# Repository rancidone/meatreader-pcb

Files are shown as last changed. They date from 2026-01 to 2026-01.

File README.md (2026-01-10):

# ESP32 Wireless Thermometer

## Overview
This project is a **custom, battery-powered ESP32-based wireless thermometer** designed for BBQ and probe-based temperature monitoring.

The goal is to build a **robust, safe, and manufacturable device** suitable for real-world use, not a development board or a proof-of-concept. The design prioritizes reliability, serviceability, and clear engineering tradeoffs over extreme miniaturization or feature creep.

---

## Project Goals
- Battery-powered operation using a single-cell Li-ion / LiPo battery
- 24+ hour runtime under typical use
- In-place battery charging via USB-C (power only)
- Wireless connectivity (Wi-Fi required, BLE optional)
- OTA firmware update capability
- Support for multiple external thermistor probes
- Safe hot-plugging of all external connectors
- Outdoor and kitchen-safe electrical robustness
- Aluminum enclosure compatibility with minimal machining tools
- Low-cost, reproducible manufacturing
- Friendly to both SMT assembly and hand soldering

---

## Design Philosophy
This project is guided by the following principles:

- **Safety first**  
  All external connections must tolerate hot-plugging, static discharge, and user error without damaging the device.

- **Manufacturable by design**  
  Components and footprints are selected with real-world assembly in mind, favoring widely available parts and avoiding unnecessary complexity.

- **Debuggable and understandable**  
  The design should be easy to inspect, measure, and troubleshoot without specialized equipment.

- **Incremental improvement**  
  Revisions build on known-good designs, preserving proven circuits while improving specific areas as needed.

---

## Non-Goals
The following are explicitly out of scope:
- USB data or USB-PD support
- Power-bank or device-charging functionality
- Ultra-miniaturized or wearable form factors
- Dev-board style layouts
- Feature-driven complexity that compromises reliability

---

## Repository Structure
This repository contains the hardware design files and supporting documentation for the project.

Typical contents include:
- KiCad schematics and PCB layouts
- Project-local symbol and footprint libraries
- Design notes and revision history
- Manufacturing and assembly references

Generated outputs (Gerbers, fabrication files, temporary caches) are not tracked unless explicitly required.

---

## Status
This repository contains an evolving hardware design with multiple revisions. Earlier revisions serve as validated references; newer revisions focus on improved power handling, manufacturability, and long-term reliability.

---

## License
This project is intended for personal, educational, and hobbyist use. Licensing details may be added as the design matures.

---

## Acknowledgements
This project draws on common, well-established embedded hardware design patterns and prioritizes practical engineering over novelty.

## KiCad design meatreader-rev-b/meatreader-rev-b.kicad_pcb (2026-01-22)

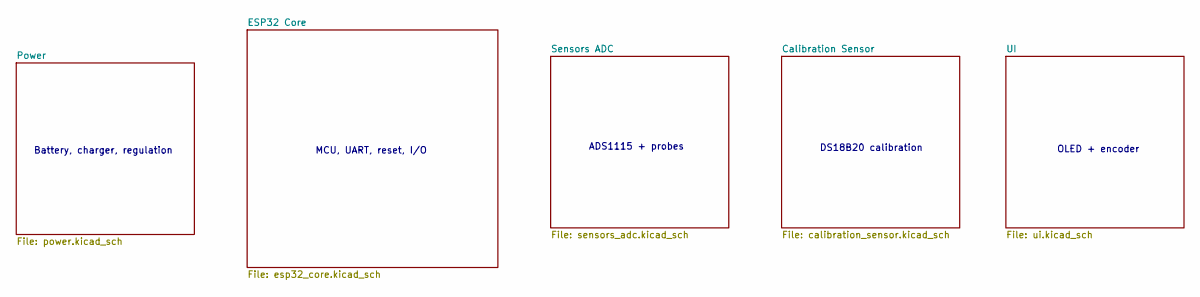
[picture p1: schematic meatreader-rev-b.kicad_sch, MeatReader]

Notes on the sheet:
MCU, UART, reset, I/O
ADS1115 + probes
OLED + encoder
Battery, charger, regulation
DS18B20 calibration

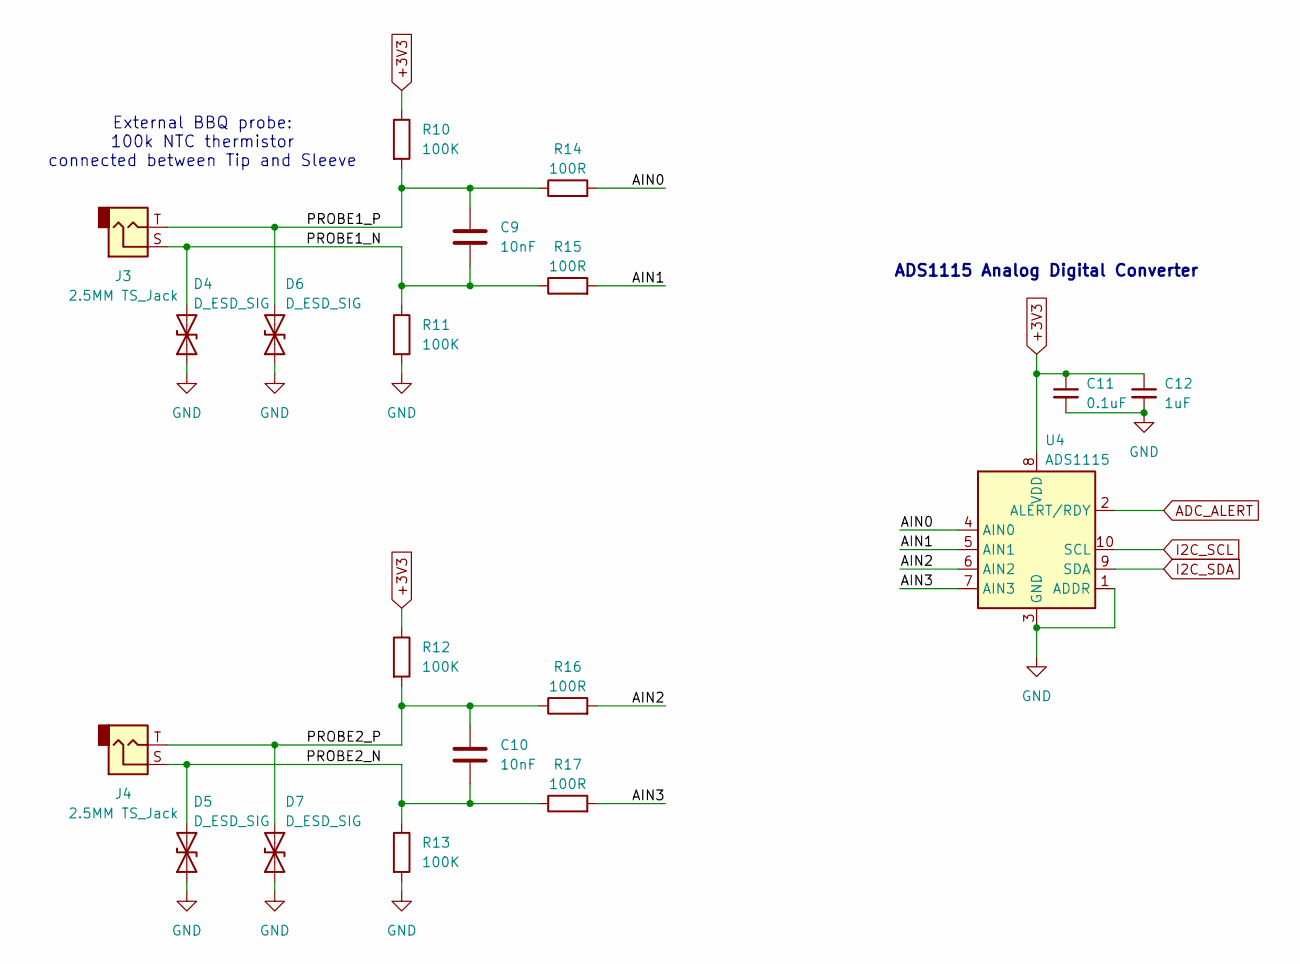
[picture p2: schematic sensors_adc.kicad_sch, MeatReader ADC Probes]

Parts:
C9, C10: 10nF; C_0603_1608Metric
C11: 0.1uF; C_0603_1608Metric
C12: 1uF; C_0603_1608Metric
D4, D5: D_ESD_SIG; D_0402_1005Metric; LCSC C20615778
D6, D7: D_ESD_SIG; D_0402_1005Metric
J3, J4: 2.5MM TS_Jack; Jack_2.5MM_PJ210B_TS; JLC_3DModel_Q 9e36057968d7478ca8658f227985305d
R10, R11, R12, R13: 100K; R_0603_1608Metric
R14, R15, R16, R17: 100R; R_0603_1608Metric
U4: ADS1115; TSSOP-10_3x3mm_P0.5mm

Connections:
+3V3: C11.1, C12.1, R10.1, R12.1, U4.8 (VDD); also elsewhere on the board
/Sensors ADC/AIN0: R14.2, U4.4 (AIN0)
/Sensors ADC/AIN1: R15.2, U4.5 (AIN1)
/Sensors ADC/AIN2: R16.2, U4.6 (AIN2)
/Sensors ADC/AIN3: R17.2, U4.7 (AIN3)
/Sensors ADC/PROBE1_N: C9.2, D4.2 (A2), J3.S, R11.1, R15.1
/Sensors ADC/PROBE1_P: C9.1, D6.2 (A2), J3.T, R10.2, R14.1
/Sensors ADC/PROBE2_N: C10.2, D5.2 (A2), J4.S, R13.1, R17.1
/Sensors ADC/PROBE2_P: C10.1, D7.2 (A2), J4.T, R12.2, R16.1
ADC_ALERT: U4.2 (ALERT/RDY); also elsewhere on the board
GND: C11.2, C12.2, D4.1 (A1), D5.1 (A1), D6.1 (A1), D7.1 (A1), R11.2, R13.2, U4.1 (ADDR), U4.3 (GND); also elsewhere on the board
I2C_SCL: U4.10 (SCL); also elsewhere on the board
I2C_SDA: U4.9 (SDA); also elsewhere on the board

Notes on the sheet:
External BBQ probe: 100k NTC thermistor connected between Tip and Sleeve
ADS1115 Analog Digital Converter

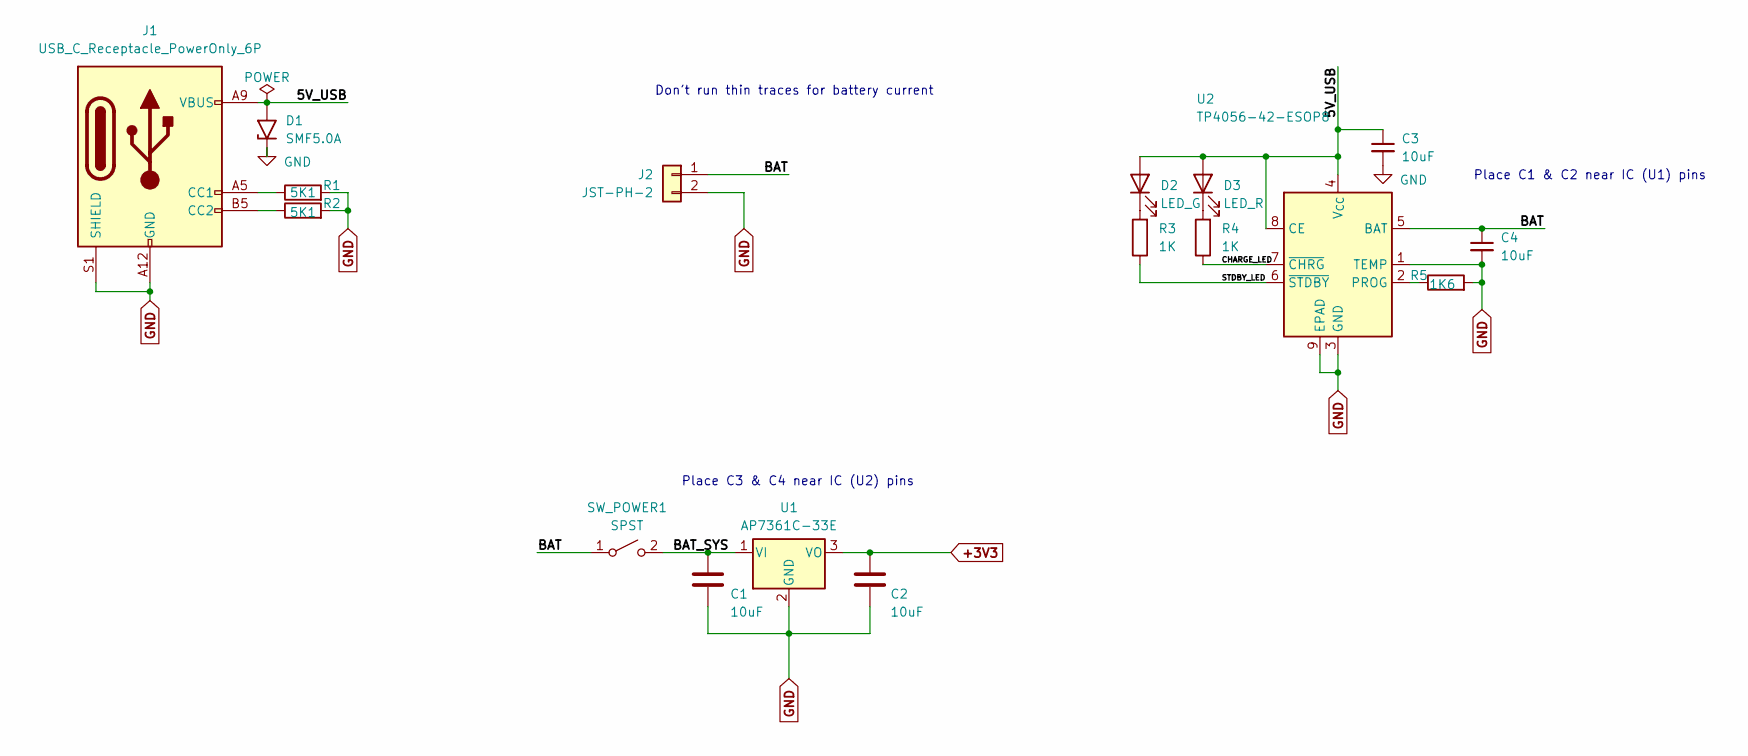
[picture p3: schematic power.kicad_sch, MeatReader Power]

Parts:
C1, C2, C3, C4: 10uF; C_0805_2012Metric
D1: SMF5.0A; D_SMF; LCSC C19077497
D2: LED_G; LED_D3.0mm
D3: LED_R; LED_D3.0mm
J1: USB_C_Receptacle_PowerOnly_6P; USB_C_Receptacle_HRO_TYPE-C-31-M-12
J2: JST-PH-2; JST_PH_B2B-PH-K_1x02_P2.00mm_Vertical
R1, R2: 5K1; R_0402_1005Metric
R3, R4: 1K; R_0402_1005Metric; LCSC C11702
R5: 1K6; R_0402_1005Metric
SW_POWER1: SPST; PinHeader_1x02_P2.54mm_Vertical
U1: AP7361C-33E; SOT-223-3_TabPin2
U2: TP4056-42-ESOP8; SOIC-8-1EP_3.9x4.9mm_P1.27mm_EP2.41x3.3mm

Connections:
+3V3: C2.1, U1.3 (VO); also elsewhere on the board
/Power/5V_USB: C3.1, D1.2 (A2), D2.2 (A), D3.2 (A), J1.A9 (VBUS), J1.B9 (VBUS), U2.4 (V_{CC}), U2.8 (CE)
/Power/BAT: C4.1, J2.1, SW_POWER1.1 (A), U2.5 (BAT)
/Power/BAT_SYS: C1.1, SW_POWER1.2 (B), U1.1 (VI)
/Power/CHARGE_LED: R4.1, U2.7 (~CHRG)
/Power/STDBY_LED: R3.1, U2.6 (~STDBY)
GND: C1.2, C2.2, C3.2, C4.2, D1.1 (A1), J1.A12 (GND), J1.B12 (GND), J1.S1 (SHIELD), J2.2, R1.2, R2.2, R5.2, U1.2 (GND), U2.1 (TEMP), U2.3 (GND), U2.9 (EPAD); also elsewhere on the board
unnamed: D2.1 (K), R3.2
unnamed: D3.1 (K), R4.2
unnamed: J1.A5 (CC1), R1.1
unnamed: J1.B5 (CC2), R2.1
unnamed: R5.1, U2.2 (PROG)

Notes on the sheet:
Don't run thin traces for battery current
Place C1 & C2 near IC (U1) pins
Place C3 & C4 near IC (U2) pins

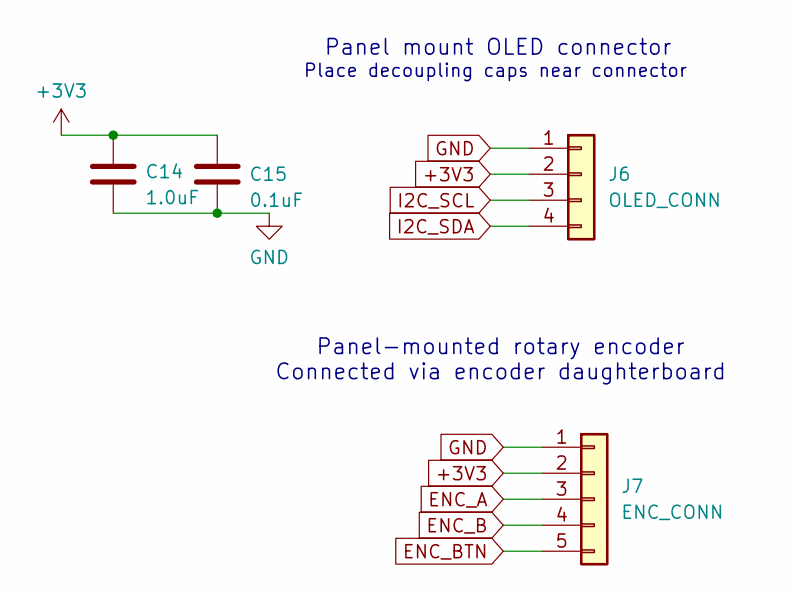
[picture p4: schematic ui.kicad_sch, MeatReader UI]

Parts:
C14: 1.0uF; C_0603_1608Metric
C15: 0.1uF; C_0603_1608Metric
J6: OLED_CONN; JST_XH_B4B-XH-AM_1x04_P2.50mm_Vertical
J7: ENC_CONN; JST_XH_B5B-XH-AM_1x05_P2.50mm_Vertical

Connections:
+3V3: C14.1, C15.1, J6.2, J7.2; also elsewhere on the board
ENC_A: J7.3; also elsewhere on the board
ENC_B: J7.4; also elsewhere on the board
ENC_BTN: J7.5; also elsewhere on the board
GND: C14.2, C15.2, J6.1, J7.1; also elsewhere on the board
I2C_SCL: J6.3; also elsewhere on the board
I2C_SDA: J6.4; also elsewhere on the board

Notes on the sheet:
Panel-mounted rotary encoder Connected via encoder daughterboard
Place decoupling caps near connector
Panel mount OLED connector

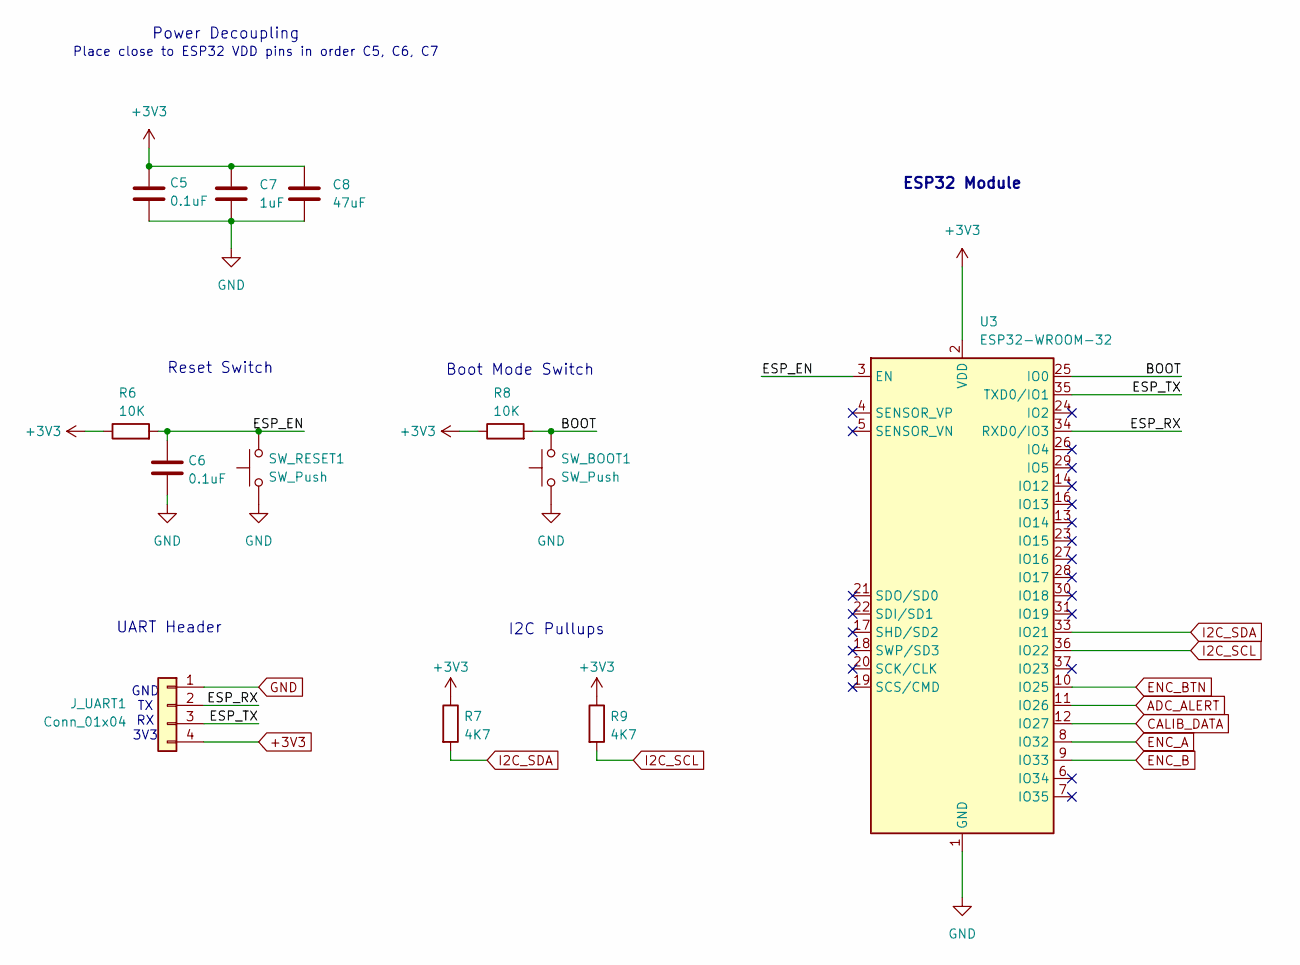
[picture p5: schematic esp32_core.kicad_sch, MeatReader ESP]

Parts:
C5, C6: 0.1uF; C_0603_1608Metric
C7: 1uF; C_0603_1608Metric
C8: 47uF; C_0805_2012Metric
J_UART1: Conn_01x04; PinHeader_1x04_P2.54mm_Vertical
R6, R8: 10K; R_0603_1608Metric
R7, R9: 4K7; R_0603_1608Metric
SW_BOOT1: SW_Push; Test_01x02
SW_RESET1: SW_Push; SW_PUSH_6mm
U3: ESP32-WROOM-32; ESP32-WROOM-32_NoThermals

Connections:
+3V3: C5.1, C7.1, C8.1, J_UART1.4, R6.1, R7.1, R8.1, R9.1, U3.2 (VDD); also elsewhere on the board
/ESP32 Core/BOOT: R8.2, SW_BOOT1.2, U3.25 (IO0)
/ESP32 Core/ESP_EN: C6.1, R6.2, SW_RESET1.2, U3.3 (EN)
/ESP32 Core/ESP_RX: J_UART1.2, U3.34 (RXD0/IO3)
/ESP32 Core/ESP_TX: J_UART1.3, U3.35 (TXD0/IO1)
ADC_ALERT: U3.11 (IO26); also elsewhere on the board
CALIB_DATA: U3.12 (IO27); also elsewhere on the board
ENC_A: U3.8 (IO32); also elsewhere on the board
ENC_B: U3.9 (IO33); also elsewhere on the board
ENC_BTN: U3.10 (IO25); also elsewhere on the board
GND: C5.2, C6.2, C7.2, C8.2, J_UART1.1, SW_BOOT1.1, SW_RESET1.1, U3.1 (GND), U3.15 (GND), U3.38 (GND), U3.39 (GND); also elsewhere on the board
I2C_SCL: R9.2, U3.36 (IO22); also elsewhere on the board
I2C_SDA: R7.2, U3.33 (IO21); also elsewhere on the board

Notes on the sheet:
GND TX RX 3V3
I2C Pullups
UART Header
Power Decoupling
Place close to ESP32 VDD pins in order C5, C6, C7
Reset Switch
Boot Mode Switch
ESP32 Module

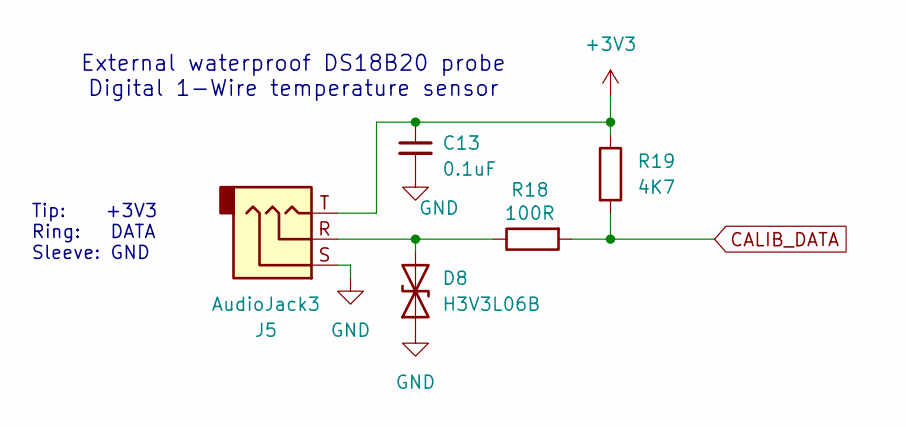
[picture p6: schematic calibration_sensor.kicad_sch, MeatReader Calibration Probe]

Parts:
C13: 0.1uF; C_0603_1608Metric
D8: H3V3L06B; D_0402_1005Metric
J5: AudioJack3; PJ-320A_TRS
R18: 100R; R_0603_1608Metric
R19: 4K7; R_0603_1608Metric

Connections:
+3V3: C13.1, J5.T, R19.1; also elsewhere on the board
CALIB_DATA: R18.2, R19.2; also elsewhere on the board
GND: C13.2, D8.1 (A1), J5.S; also elsewhere on the board
unnamed: D8.2 (A2), J5.R, R18.1

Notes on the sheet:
External waterproof DS18B20 probe Digital 1-Wire temperature sensor
Tip: +3V3 Ring: DATA Sleeve: GND

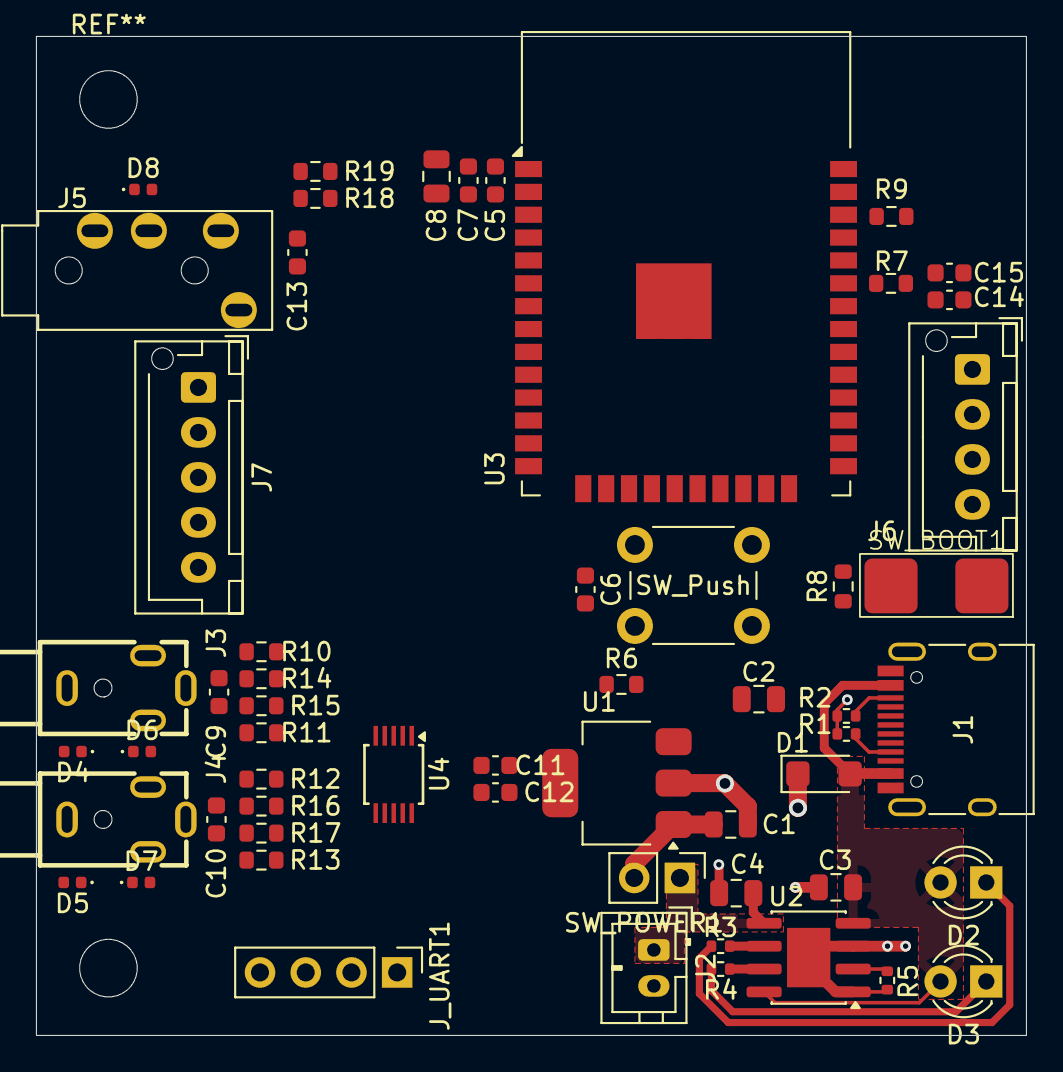
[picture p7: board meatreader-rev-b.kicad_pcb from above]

Board: 2 copper layers, 55.0 x 55.5 mm, 57 parts (0 on the bottom side), 32 nets.

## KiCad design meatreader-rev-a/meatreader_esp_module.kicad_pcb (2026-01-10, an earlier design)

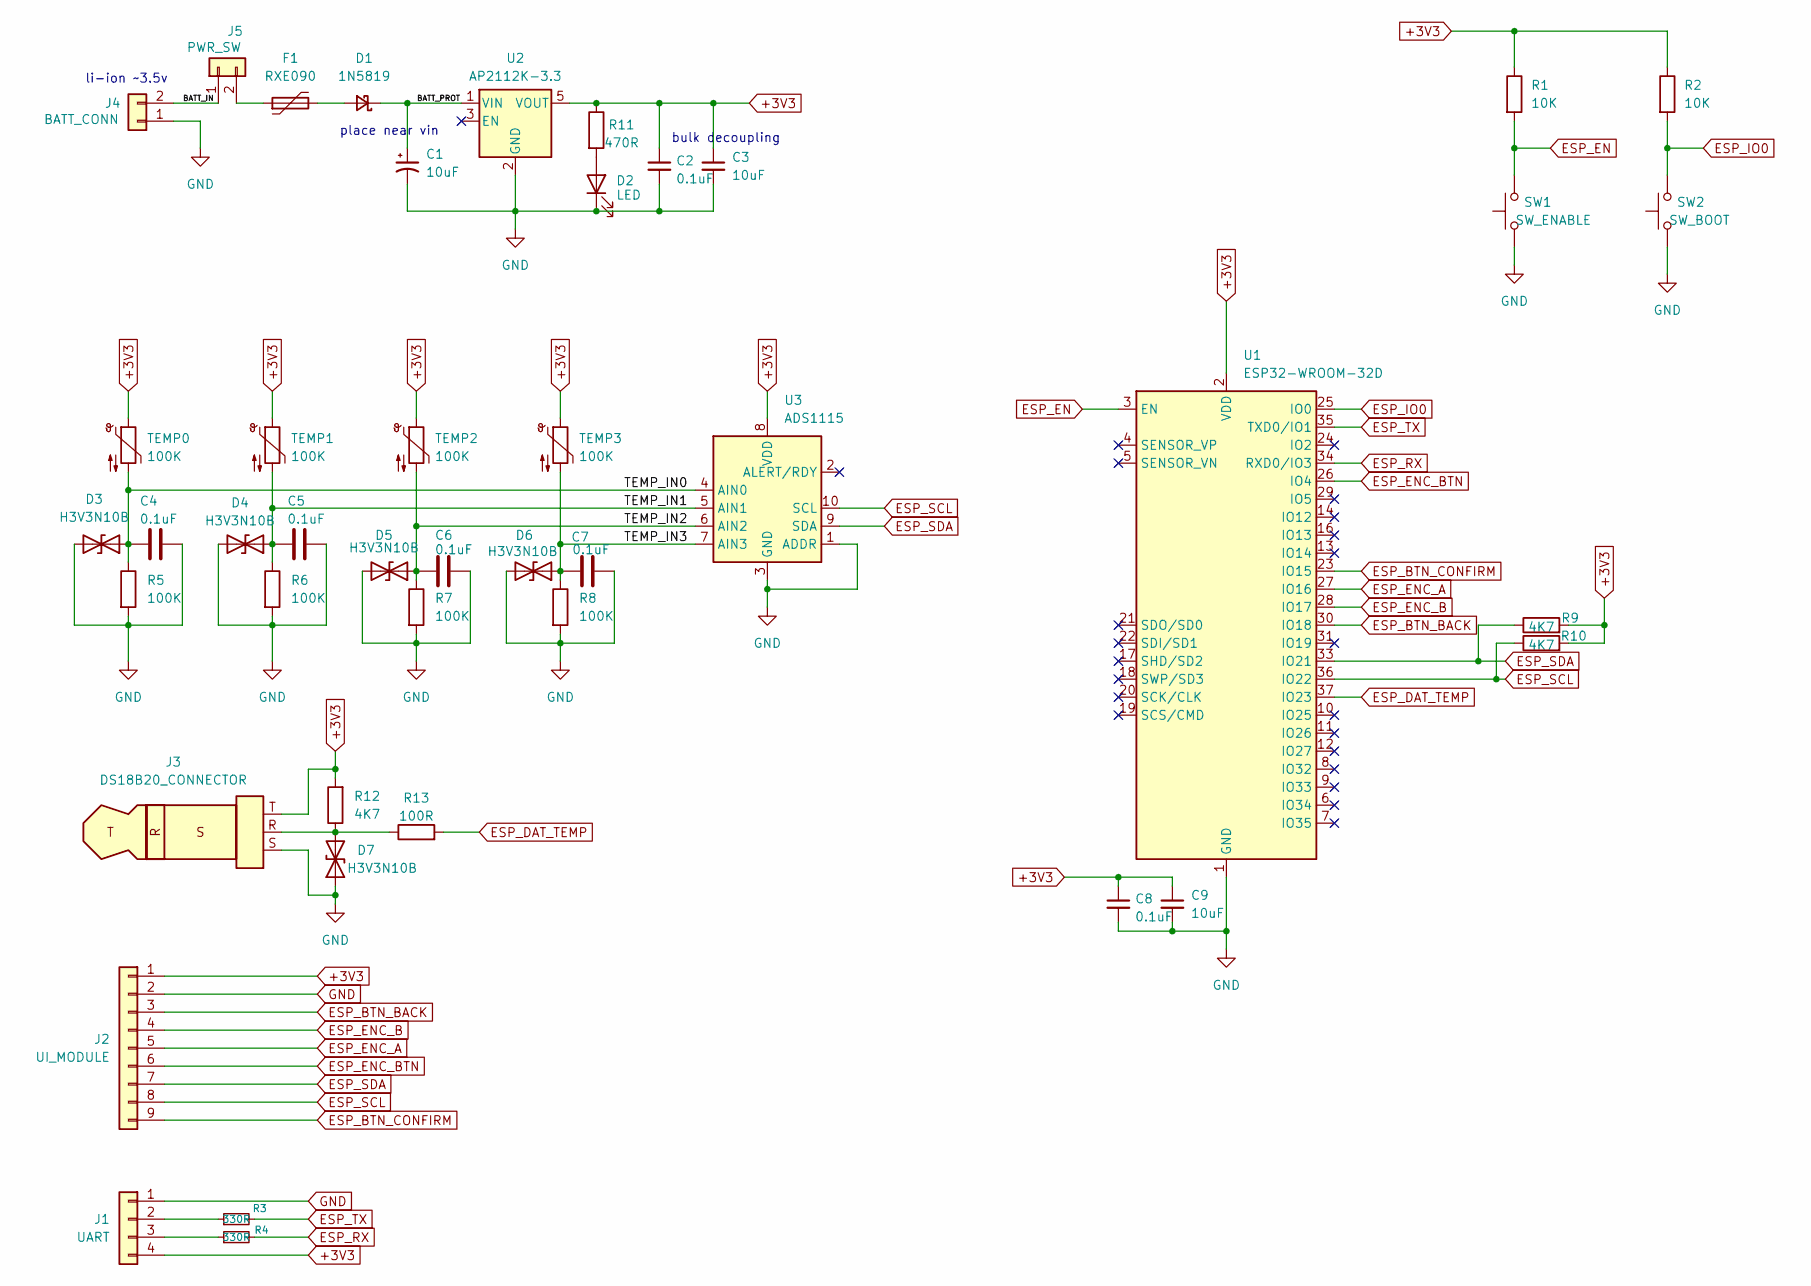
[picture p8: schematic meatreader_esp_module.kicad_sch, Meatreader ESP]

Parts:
C1, C9: 10uF; CP_Radial_D5.0mm_P2.50mm
C2, C4, C5, C6, C7, C8: 0.1uF; C_0603_1608Metric; LCSC C14663
C3: 10uF; C_0603_1608Metric; LCSC C19702
D1: 1N5819; D_DO-41_SOD81_P10.16mm_Horizontal
D2: LED; LED_0603_1608Metric; LCSC C2286
D3, D4, D5, D6, D7: H3V3N10B; D_SOD-882; LCSC C20617909
F1: RXE090; C_Axial_L5.1mm_D3.1mm_P7.50mm_Horizontal
J1: UART; PinHeader_1x04_P2.54mm_Vertical
J2: UI_MODULE; PinHeader_1x09_P2.54mm_Vertical
J3: DS18B20_CONNECTOR; PJ-320A_TRS
J4: BATT_CONN; JST_PH_B2B-PH-K_1x02_P2.00mm_Vertical
J5: PWR_SW; PinHeader_1x02_P2.54mm_Vertical
R1: 10K; R_0603_1608Metric; LCSC C25804
R2: 10K; R_Axial_DIN0207_L6.3mm_D2.5mm_P7.62mm_Horizontal
R3, R4: 330R; R_Axial_DIN0207_L6.3mm_D2.5mm_P7.62mm_Horizontal
R5, R6, R7, R8: 100K; R_Axial_DIN0207_L6.3mm_D2.5mm_P7.62mm_Horizontal
R9, R10, R12: 4K7; R_Axial_DIN0207_L6.3mm_D2.5mm_P7.62mm_Horizontal
R11: 470R; R_Axial_DIN0207_L6.3mm_D2.5mm_P7.62mm_Horizontal
R13: 100R; R_Axial_DIN0207_L6.3mm_D2.5mm_P7.62mm_Horizontal
SW1: SW_ENABLE; SW_PUSH_6mm_H5mm
SW2: SW_BOOT; SW_PUSH_6mm_H5mm
TEMP0, TEMP1, TEMP2, TEMP3: 100K; Jack_2.5MM_PJ210B; JLC_3DModel_Q 9e36057968d7478ca8658f227985305d
U1: ESP32-WROOM-32D; ESP32_D0WD
U2: AP2112K-3.3; SOT-23-5; LCSC C23380830
U3: ADS1115; TSSOP-10_3x3mm_P0.5mm; LCSC C37593

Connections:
+3V3: C2.1, C3.1, C8.1, C9.1, J1.4 (VCC), J2.1, J3.T, R1.1, R2.1, R9.2, R10.2, R11.1, R12.2, TEMP0.1, TEMP1.1, TEMP2.1, TEMP3.1, U1.2 (VDD), U2.5 (VOUT), U3.8 (VDD)
/BATT_IN: J4.2, J5.1
/BATT_PROT: C1.1, D1.1 (K), U2.1 (VIN)
/TEMP_IN0: C4.1, D3.1 (A1), R5.1, TEMP0.2, U3.4 (AIN0)
/TEMP_IN1: C5.1, D4.1 (A1), R6.1, TEMP1.2, U3.5 (AIN1)
/TEMP_IN2: C6.1, D5.1 (A1), R7.1, TEMP2.2, U3.6 (AIN2)
/TEMP_IN3: C7.1, D6.1 (A1), R8.1, TEMP3.2, U3.7 (AIN3)
ESP_BTN_BACK: J2.3, U1.30 (IO18)
ESP_BTN_CONFIRM: J2.9, U1.23 (IO15)
ESP_DAT_TEMP: R13.2, U1.37 (IO23)
ESP_EN: R1.2, SW1.2, U1.3 (EN)
ESP_ENC_A: J2.5, U1.27 (IO16)
ESP_ENC_B: J2.4, U1.28 (IO17)
ESP_ENC_BTN: J2.6, U1.26 (IO4)
ESP_IO0: R2.2, SW2.2, U1.25 (IO0)
ESP_RX: R4.2, U1.34 (RXD0/IO3)
ESP_SCL: J2.8, R10.1, U1.36 (IO22), U3.10 (SCL)
ESP_SDA: J2.7, R9.1, U1.33 (IO21), U3.9 (SDA)
ESP_TX: R3.2, U1.35 (TXD0/IO1)
GND: C1.2, C2.2, C3.2, C4.2, C5.2, C6.2, C7.2, C8.2, C9.2, D2.1 (K), D3.2 (A2), D4.2 (A2), D5.2 (A2), D6.2 (A2), D7.1 (A1), J1.1 (GND), J2.2, J3.S, J4.1, R5.2, R6.2, R7.2, R8.2, SW1.1, SW2.1, U1.1 (GND), U1.15 (GND), U1.38 (GND), U1.39 (GND), U2.2 (GND), U3.1 (ADDR), U3.3 (GND)
unnamed: D1.2 (A), F1.2
unnamed: D2.2 (A), R11.2
unnamed: D7.2 (A2), J3.R, R12.1, R13.1
unnamed: J1.3 (RX), R4.1
unnamed: J1.2 (TX), R3.1
unnamed: F1.1, J5.2

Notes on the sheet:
place near vin
li-ion ~3.5v
bulk decoupling

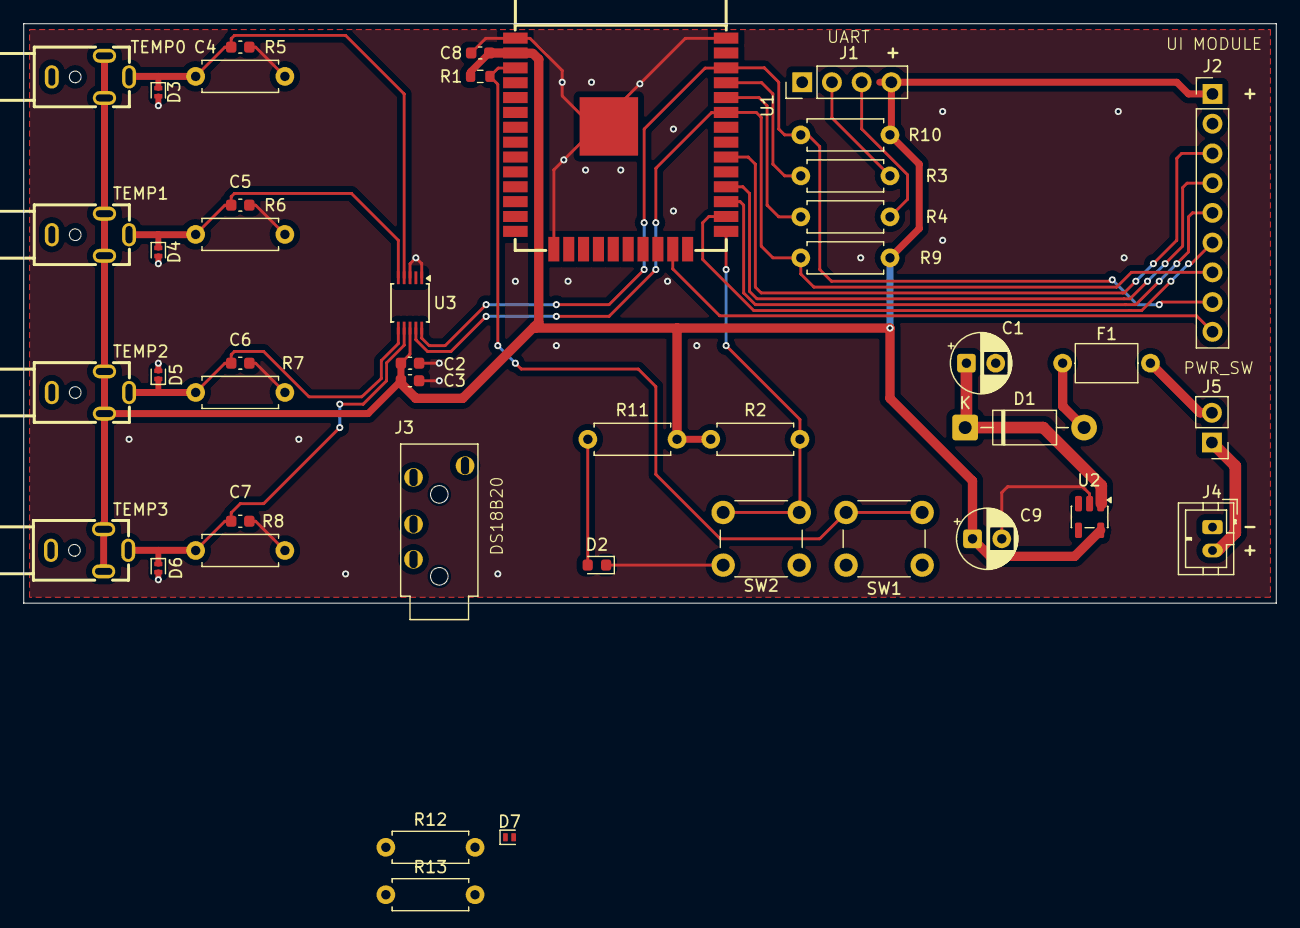
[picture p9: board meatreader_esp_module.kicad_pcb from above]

Board: 2 copper layers, 107.0 x 49.5 mm, 44 parts (0 on the bottom side), 26 nets.

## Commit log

2026-01-10 Initial commit, legacy version. Incomplete.
    [meatreader_esp_module.kicad_pcb, meatreader_esp_module.kicad_sch]
2026-01-10 Move rev-a to a folder, create rev-b project
    [meatreader-rev-b.kicad_pcb, meatreader-rev-b.kicad_sch, meatreader_esp_module.kicad_pcb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]
2026-01-15 Power and ESP core
    [esp32_core.kicad_sch, meatreader-rev-b.kicad_sch, power.kicad_sch]
2026-01-17 rev-b initial commit
    [calibration_sensor.kicad_sch, encoder_board.kicad_sch, meatreader-rev-b.kicad_sch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]
2026-01-22 start routing
    [calibration_sensor.kicad_sch, esp32_core.kicad_sch, meatreader-rev-b.kicad_pcb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]
